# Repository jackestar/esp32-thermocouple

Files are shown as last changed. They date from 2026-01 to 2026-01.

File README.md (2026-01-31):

<h3 align="center">ESP32-S2 Based Thermocouple Dirver</h3>

<div align="center">
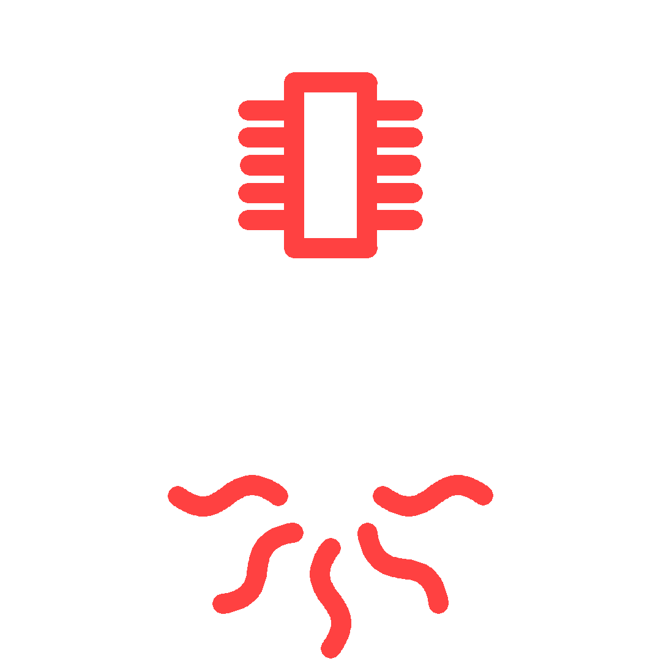
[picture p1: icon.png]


</div>

### Materials

* ESP32-S2
* LM356
* AD620AN
* ~~LM35~~
* [TC33X-2-103E](https://componentsearchengine.com/part-view/TC33X-2-103E/Bourns) (or equivalent footprint)

### Proyect Structure

**IDF code**
FLAGS: 
 * TEST (breadboard/PCB)
 * DEBUG (SERIAL OUTPUT)

**Kicad**

> The last version is made for a 1-wire temperature module, the PCB can include LM35/LM335 like the example in [Commit 6ab5541](https://github.com/jackestar/esp32-thermocouple/commit/6ab55410f83fd76fe158129e17a911ef169d20fd)

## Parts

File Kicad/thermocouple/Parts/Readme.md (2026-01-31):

[TC33X-2-103E](https://componentsearchengine.com/part-view/TC33X-2-103E/Bourns) (or equivalent footprint)

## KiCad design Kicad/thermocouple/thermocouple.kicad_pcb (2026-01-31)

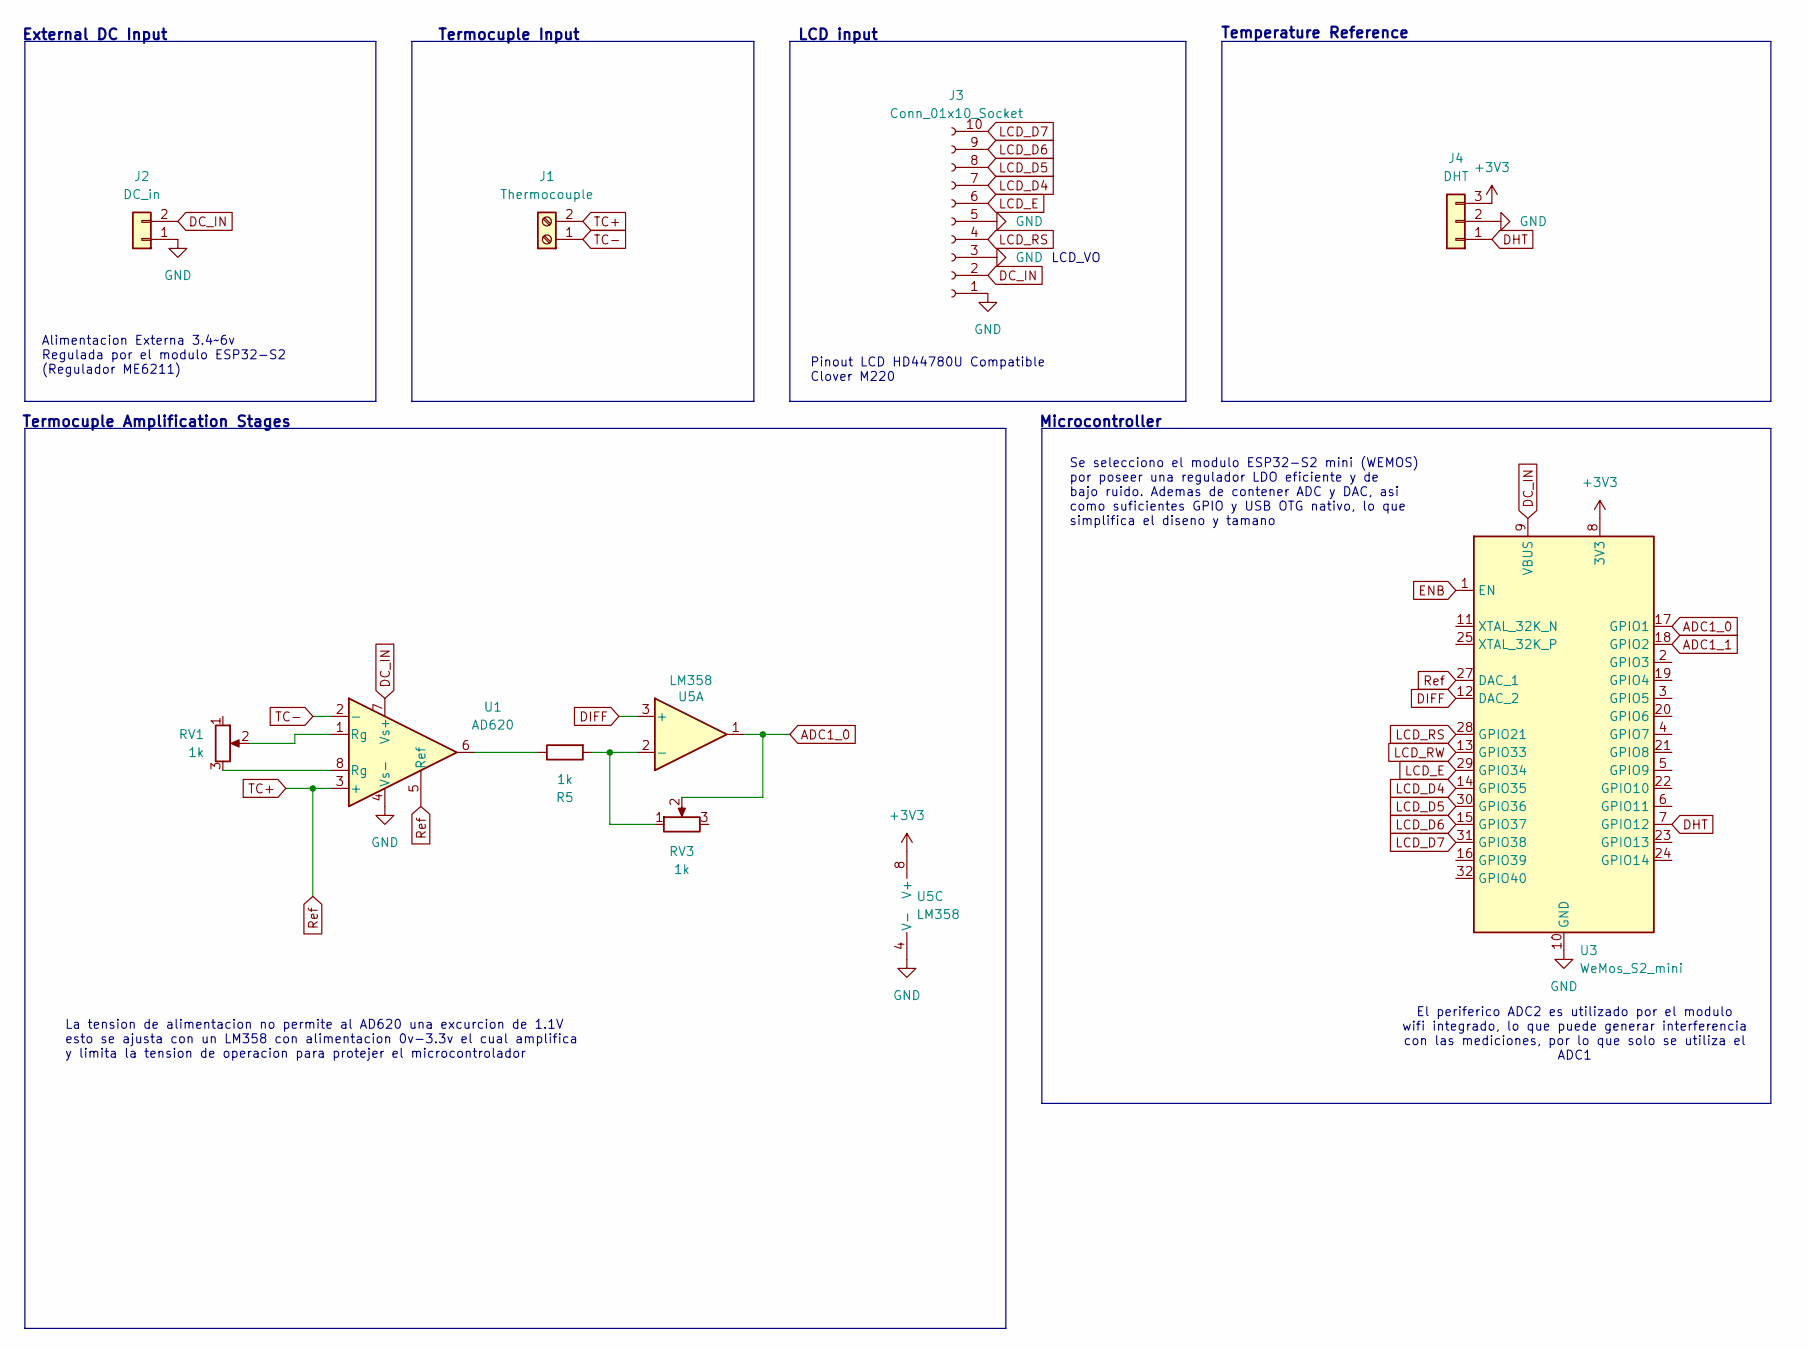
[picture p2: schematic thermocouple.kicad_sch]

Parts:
J1: Thermocouple; TerminalBlock_MaiXu_MX126-5.0-02P_1x02_P5.00mm
J2: DC_in; PinHeader_1x02_P2.54mm_Vertical
J3: Conn_01x10_Socket; PinSocket_1x10_P2.54mm_Vertical
J4: DHT; PinHeader_1x03_P2.54mm_Vertical
R5: 1k; R_1206_3216Metric_Pad1.30x1.75mm_HandSolder
RV1, RV3: 1k; Potentiometer_Bourns_TC33X_Vertical
U1: AD620; DIP-8_W7.62mm_Socket_LongPads
U3: WeMos_S2_mini; WEMOS_S2_mini
U5: LM358; SOIC-8_3.9x4.9mm_P1.27mm

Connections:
+3V3: J4.3, U3.8 (3V3), U5.8 (V+)
ADC1_0: RV3.2, U3.17 (GPIO1), U5.1
ADC1_1: U3.18 (GPIO2)
DC_IN: J2.2, J3.2, U1.7 (Vs+), U3.9 (VBUS)
DHT: J4.1, U3.7 (GPIO12)
DIFF: U3.12 (DAC_2), U5.3 (+)
ENB: U3.1 (EN)
GND: J2.1, J3.1, J3.3, J3.5, J4.2, U1.4 (Vs-), U3.10 (GND), U3.26 (GND), U5.4 (V-)
LCD_D4: J3.7, U3.14 (GPIO35)
LCD_D5: J3.8, U3.30 (GPIO36)
LCD_D6: J3.9, U3.15 (GPIO37)
LCD_D7: J3.10, U3.31 (GPIO38)
LCD_E: J3.6, U3.29 (GPIO34)
LCD_RS: J3.4, U3.28 (GPIO21)
LCD_RW: U3.13 (GPIO33)
unnamed: R5.1, U1.6
unnamed: RV1.2, U1.1 (Rg)
unnamed: RV1.3, U1.8 (Rg)
unnamed: R5.2, RV3.1, U5.2 (-)
Ref: J1.2, U1.3 (+), U1.5 (Ref), U3.27 (DAC_1)
TC-: J1.1, U1.2 (-)

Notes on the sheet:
Termocuple Input
LCD input
La tension de alimentacion no permite al AD620 una excurcion de 1.1V esto se ajusta con un LM358 con alimentacion 0v-3.3v el cual amplifica y limita la tension de operacion para protejer el microcontrolador
Se selecciono el modulo ESP32-S2 mini (WEMOS) por poseer una regulador LDO eficiente y de bajo ruido. Ademas de contener ADC y DAC, asi como suficientes GPIO y USB OTG nativo, lo que simplifica el diseno y tamano
External DC Input
Microcontroller
Alimentacion Externa 3.4~6v Regulada por el modulo ESP32-S2 (Regulador ME6211)
LCD_VO
Termocuple Amplification Stages
Temperature Reference
Pinout LCD HD44780U Compatible Clover M220
El periferico ADC2 es utilizado por el modulo wifi integrado, lo que puede generar interferencia con las mediciones, por lo que solo se utiliza el ADC1

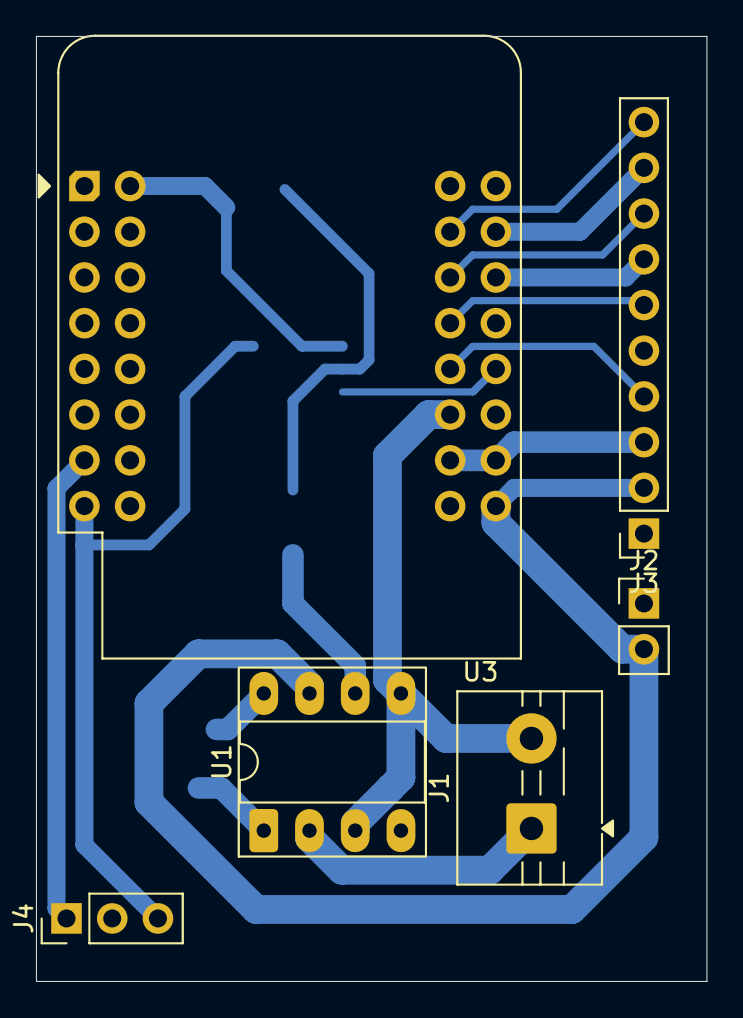
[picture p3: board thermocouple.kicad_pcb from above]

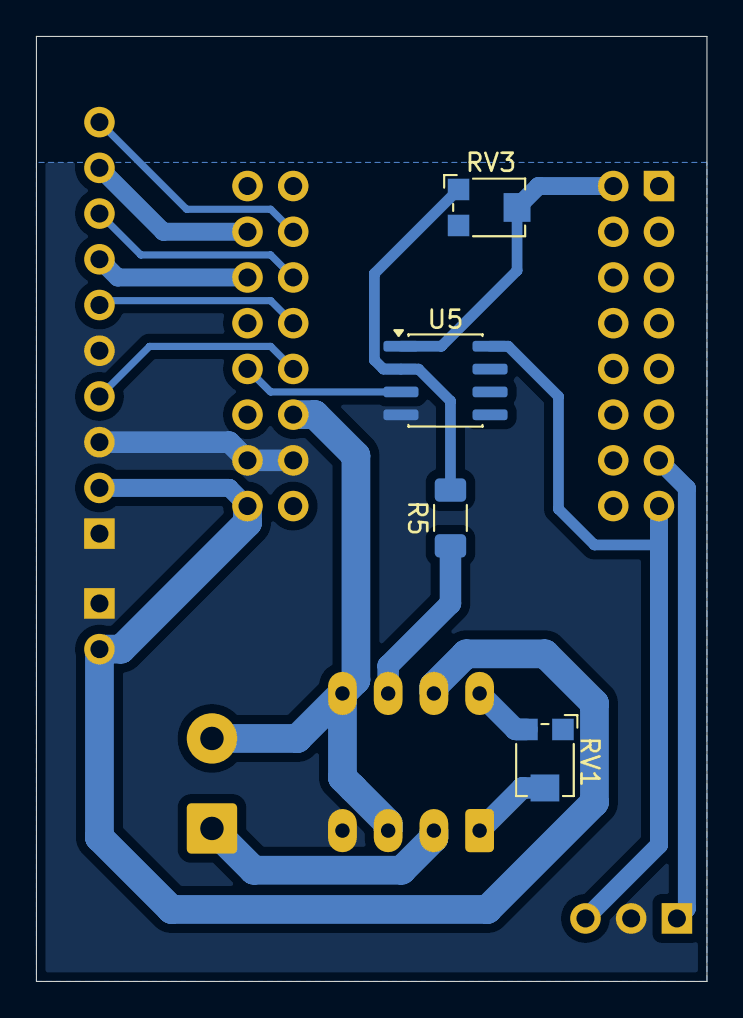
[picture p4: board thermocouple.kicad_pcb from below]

Board: 2 copper layers, 37.2 x 52.5 mm, 10 parts (4 on the bottom side), 18 nets.

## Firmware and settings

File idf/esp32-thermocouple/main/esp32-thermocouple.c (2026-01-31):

#include <stdio.h>
#include <inttypes.h>
#include <stdlib.h>

#include <hd44780.h>
#include <esp_idf_lib_helpers.h>

#include <freertos/FreeRTOS.h>
#include <freertos/task.h>
#include <freertos/semphr.h>

#include "esp_adc/adc_oneshot.h"
#include "esp_check.h"
#include "esp_log.h"

#include "dht.h"

#include "driver/dac_oneshot.h"
#include "nvs_flash.h"
#include "esp_netif.h"
#include "esp_event.h"
#include "esp_wifi.h"
#include "esp_http_server.h"
#include "esp_err.h"
#include <string.h>

uint8_t DAC_DIFF = 115; //180
uint8_t DAC_VGND = 215;

float TER_BIAS = 408.4583; // 0-max_raw
int TER_PROP = -568.8889;

// Breadboard test have another easier pin out
#define TEST

#ifdef TEST

#define TER_ADC 8
#define AMB_DHT 5

hd44780_t lcd = {
    .write_cb = NULL,
    .font = HD44780_FONT_5X8,
    .lines = 2,
    .pins = {
        .rs = GPIO_NUM_7,
        .e = GPIO_NUM_3,
        .d4 = GPIO_NUM_8,
        .d5 = GPIO_NUM_6,
        .d6 = GPIO_NUM_4,
        .d7 = GPIO_NUM_2,
        .bl = HD44780_NOT_USED}};

#else

#define TER_ADC 2
#define AMB_DHT 4

hd44780_t lcd = {
    .write_cb = NULL,
    .font = HD44780_FONT_5X8,
    .lines = 2,
    .pins = {
        .rs = GPIO_NUM_21,
        .e = GPIO_NUM_34,
        .d4 = GPIO_NUM_35,
        .d5 = GPIO_NUM_36,
        .d6 = GPIO_NUM_37,
        .d7 = GPIO_NUM_38,
        .bl = HD44780_NOT_USED}};

#define TER_ADC 2
#define AMB_DHT 4

#define LCD_RW 33
#define LCD_VO 16

#endif

#define EXAMPLE_DAC_CHAN0_ADC_CHAN ADC_CHANNEL_6 // GPIO17, same as DAC channel 0
#define EXAMPLE_DAC_CHAN1_ADC_CHAN ADC_CHANNEL_7 // GPIO18, same as DAC channel 1

#define debug 1

static const uint8_t amb_sym[8] = {0b00000100,
                                   0b00000100,
                                   0b00011111,
                                   0b00001110,
                                   0b00000100,
                                   0b00011111,
                                   0b00000100,
                                   0b00000100};
static const uint8_t ter_sym[8] = {0b00011000,
                                   0b00000100,
                                   0b00000010,
                                   0b00000001,
                                   0b00000010,
                                   0b00000100,
                                   0b00011000,
                                   0b00000000};
static const uint8_t cen_sym[8] = {0b00011000,
                                   0b00011000,
                                   0b00000011,
                                   0b00000100,
                                   0b00000100,
                                   0b00000100,
                                   0b00000011,
                                   0b00000000};

float amb_tem = 27.00;
float ter_tem = 27.00;
float ADC_ACUM = 0;
static adc_oneshot_unit_handle_t adc_handle = NULL;
static dac_oneshot_handle_t dac_chan0_handle = NULL;
static dac_oneshot_handle_t dac_chan1_handle = NULL;

/* Webserver / Wi-Fi globals */
static httpd_handle_t server = NULL;
static SemaphoreHandle_t config_mutex = NULL;

/* Simple root page (no styling) */
static const char *index_html =
    "<!doctype html>"
    "<html><head><meta charset=\"utf-8\"></head><body>"
    "<h3>ESP32 Thermocouple</h3>"
    "<div>Ambient: <span id=\"amb\">--</span> &deg;C</div>"
    "<div>Thermocouple: <span id=\"ter\">--</span> &deg;C</div>"
    "<hr>"
    "<div>DAC_DIFF: <input id=\"DAC_DIFF_in\" size=6> <p id=\"DAC_DIFF_val\">--</p></div>"
    "<div>DAC_VGND: <input id=\"DAC_VGND_in\" size=6> <p id=\"DAC_VGND_val\">--</p></div>"
    "<div>TER_BIAS: <input id=\"TER_BIAS_in\" size=6> <p id=\"TER_BIAS_val\">--</p></div>"
    "<div>TER_PROP: <input id=\"TER_PROP_in\" size=6> <p id=\"TER_PROP_val\">--</p></div>"
    "<div>ADC_ACUM: <input id=\"ADC_ACUM_in\" size=8> <p id=\"ADC_ACUM_val\">--</p></div>"
    "<div><button onclick=\"apply()\">Apply</button></div>"
    "<script>"
    "async function fetchState(){"
    " const r=await fetch('/api/state');"
    " const j=await r.json();"
    " document.getElementById('amb').textContent=j.amb_tem.toFixed(2);"
    " document.getElementById('ter').textContent=j.ter_tem.toFixed(2);"
    " document.getElementById('DAC_DIFF_val').textContent = j.DAC_DIFF;"
    " document.getElementById('DAC_VGND_val').textContent = j.DAC_VGND;"
    " document.getElementById('TER_BIAS_val').textContent = j.TER_BIAS.toFixed(2);"
    " document.getElementById('TER_PROP_val').textContent = j.TER_PROP.toFixed(2);"
    " document.getElementById('ADC_ACUM_val').textContent = j.ADC_ACUM.toFixed(3);"
    "}"
    "async function apply(){"
    " const params=[];"
    " const mappings=[['DAC_DIFF_in','DAC_DIFF'],['DAC_VGND_in','DAC_VGND'],['TER_BIAS_in','TER_BIAS'],['TER_PROP_in','TER_PROP'],['ADC_ACUM_in','ADC_ACUM']];"
    " mappings.forEach(pair=>{ const v=document.getElementById(pair[0]).value; if(v!=='') params.push(encodeURIComponent(pair[1])+'='+encodeURIComponent(v)); });"
    " await fetch('/api/set?'+params.join('&'));"
    " setTimeout(fetchState,200);"
    "}"
    "setInterval(fetchState,1000); fetchState();"
    "</script>"
    "</body></html>";

/* Handler: root page */
static esp_err_t root_get_handler(httpd_req_t *req)
{
    httpd_resp_set_type(req, "text/html");
    httpd_resp_send(req, index_html, HTTPD_RESP_USE_STRLEN);
    return ESP_OK;
}

/* Handler: /api/state -> JSON with current values */
static esp_err_t api_state_get_handler(httpd_req_t *req)
{
    char buf[256];
    float dac_diff, dac_vgnd, ter_bias, ter_prop, adc_acum, amb, ter;

    if (config_mutex) xSemaphoreTake(config_mutex, portMAX_DELAY);
    dac_diff = DAC_DIFF;
    dac_vgnd = DAC_VGND;
    ter_bias = TER_BIAS;
    ter_prop = TER_PROP;
    adc_acum = ADC_ACUM;
    amb = amb_tem;
    ter = ter_tem;
    if (config_mutex) xSemaphoreGive(config_mutex);

    int len = snprintf(buf, sizeof(buf), "{\"DAC_DIFF\":%.0f,\"DAC_VGND\":%.0f,\"TER_BIAS\":%.2f,\"TER_PROP\":%.2f,\"ADC_ACUM\":%.3f,\"amb_tem\":%.2f,\"ter_tem\":%.2f}", dac_diff, dac_vgnd, ter_bias, ter_prop, adc_acum, amb, ter);
    httpd_resp_set_type(req, "application/json");
    httpd_resp_send(req, buf, len);
    return ESP_OK;
}

/* Handler: /api/set?KEY=VALUE&... -> update variables */
static esp_err_t api_set_get_handler(httpd_req_t *req)
{
    char buf[256];
    if (httpd_req_get_url_query_str(req, buf, sizeof(buf)) == ESP_OK)
    {
        char val[64];
        if (config_mutex) xSemaphoreTake(config_mutex, portMAX_DELAY);

        if (httpd_query_key_value(buf, "DAC_DIFF", val, sizeof(val)) == ESP_OK)
            DAC_DIFF = (uint8_t)atoi(val);
        if (httpd_query_key_value(buf, "DAC_VGND", val, sizeof(val)) == ESP_OK)
            DAC_VGND = (uint8_t)atoi(val);
        if (httpd_query_key_value(buf, "TER_BIAS", val, sizeof(val)) == ESP_OK)
            TER_BIAS = atof(val);
        if (httpd_query_key_value(buf, "TER_PROP", val, sizeof(val)) == ESP_OK)
            TER_PROP = atoi(val);
        if (httpd_query_key_value(buf, "ADC_ACUM", val, sizeof(val)) == ESP_OK)
            ADC_ACUM = atof(val);

        if (config_mutex) xSemaphoreGive(config_mutex);
    }

    httpd_resp_sendstr(req, "OK");
    return ESP_OK;
}

/* Start the webserver and register URIs */
static httpd_handle_t start_webserver(void)
{
    httpd_config_t config = HTTPD_DEFAULT_CONFIG();
    httpd_handle_t server = NULL;
    if (httpd_start(&server, &config) == ESP_OK)
    {
        httpd_uri_t uri_root = {
            .uri = "/",
            .method = HTTP_GET,
            .handler = root_get_handler,
            .user_ctx = NULL};
        httpd_register_uri_handler(server, &uri_root);

        httpd_uri_t uri_state = {
            .uri = "/api/state",
            .method = HTTP_GET,
            .handler = api_state_get_handler,
            .user_ctx = NULL};
        httpd_register_uri_handler(server, &uri_state);

        httpd_uri_t uri_set = {
            .uri = "/api/set",
            .method = HTTP_GET,
            .handler = api_set_get_handler,
            .user_ctx = NULL};
        httpd_register_uri_handler(server, &uri_set);
    }
    return server;
}

/* Wi-Fi soft AP initializer (open AP) */
static void wifi_init_softap(void)
{
    esp_err_t ret = nvs_flash_init();
    if (ret == ESP_ERR_NVS_NO_FREE_PAGES || ret == ESP_ERR_NVS_NEW_VERSION_FOUND) {
        nvs_flash_erase();
        nvs_flash_init();
    }

    esp_netif_init();
    esp_event_loop_create_default();
    esp_netif_create_default_wifi_ap();

    wifi_init_config_t cfg = WIFI_INIT_CONFIG_DEFAULT();
    esp_wifi_init(&cfg);

    wifi_config_t wifi_config = {0};
    snprintf((char *)wifi_config.ap.ssid, sizeof(wifi_config.ap.ssid), "%s", "ESP32_THERMO");
    wifi_config.ap.ssid_len = strlen("ESP32_THERMO");
    wifi_config.ap.channel = 1;
    wifi_config.ap.max_connection = 4;
    wifi_config.ap.authmode = WIFI_AUTH_OPEN;

    esp_wifi_set_mode(WIFI_MODE_AP);
    esp_wifi_set_config(WIFI_IF_AP, &wifi_config);
    esp_wifi_start();
}

void lcd_config()
{
    ESP_ERROR_CHECK(hd44780_init(&lcd));
}

void dht_task(void *pvParameters)
{
    gpio_set_pull_mode(AMB_DHT, GPIO_PULLUP_ONLY);
    while (1)
    {
        ESP_ERROR_CHECK(dht_read_float_data(DHT_TYPE_AM2301, AMB_DHT, NULL, &amb_tem));
        vTaskDelay(pdMS_TO_TICKS(2000));
    }
}

void lcd_task(void *pvParameters)
{
    hd44780_upload_character(&lcd, 0, amb_sym);
    hd44780_upload_character(&lcd, 1, ter_sym);
    hd44780_upload_character(&lcd, 2, cen_sym);

    hd44780_gotoxy(&lcd, 0, 0);
    hd44780_puts(&lcd, "\x08      \x0A");
    hd44780_gotoxy(&lcd, 0, 1);
    hd44780_puts(&lcd, "\x09      \x0A");

    while (1)
    {
        char buf[16];

        hd44780_gotoxy(&lcd, 2, 1);
        snprintf(buf, sizeof(buf), "%.2f", ter_tem);
        buf[sizeof(buf) - 1] = 0;
        hd44780_puts(&lcd, buf);

        hd44780_gotoxy(&lcd, 2, 0);
        snprintf(buf, sizeof(buf), "%.2f", amb_tem);
        buf[sizeof(buf) - 1] = 0;
        hd44780_puts(&lcd, buf);

        vTaskDelay(pdMS_TO_TICKS(250));
    }
}

#define BLINK_GPIO 15

void led_blink(void *pvParameters)
{
    gpio_reset_pin(BLINK_GPIO);
    gpio_set_direction(BLINK_GPIO, GPIO_MODE_OUTPUT);

    while (1)
    {
        // Turn LED ON
        gpio_set_level(BLINK_GPIO, 1);
        vTaskDelay(1000 / portTICK_PERIOD_MS); // Delay 1 second

        // Turn LED OFF
        gpio_set_level(BLINK_GPIO, 0);
        vTaskDelay(1000 / portTICK_PERIOD_MS); // Delay 1 second
    }
}

#define SPS 100

void adc_task(void *pvParameters)
{
    printf("ADC task\n");
    adc_oneshot_chan_cfg_t chan_cfg = {
        .bitwidth = ADC_BITWIDTH_DEFAULT,
        .atten = ADC_ATTEN_DB_12,
    };

    ESP_ERROR_CHECK(adc_oneshot_config_channel(adc_handle, TER_ADC, &chan_cfg));
    printf("ADC task: LOOP\n");
    int acumulator[SPS] = {0};
    uint8_t counter = 0;
    while (1)
    {
        int raw = 0;
        esp_err_t ret = adc_oneshot_read(adc_handle, TER_ADC, &raw);
        if (ret == ESP_OK)
        {
            const int max_raw = 8192; /* 13-bit resolution */

            counter++;
            if (counter == SPS)
                counter = 0;

            acumulator[counter] = raw;
            if (counter == SPS - 1)
            {
                ADC_ACUM = 0;
                for (uint8_t i = 0; i < SPS; i++)
                    ADC_ACUM += acumulator[i];
                ADC_ACUM /= SPS;

                const float cast = (max_raw - ADC_ACUM) * TER_PROP;
                ter_tem = amb_tem + TER_BIAS + cast / max_raw;

                if (debug)
                {
                    printf("ADC %f\n", ADC_ACUM);
                    printf("AMB %f\n", amb_tem);
                }
            }
        }
        else
        {
            printf("ADC task fail!!!\n");
            ESP_LOGW("adc_task", "adc read failed: %d", ret);
        }

        vTaskDelay(pdMS_TO_TICKS(1000 / SPS));
    }
}

void dac_update_task(void *pvParameters)
{
    while (1)
    {
        uint8_t diff = 0, vgnd = 0;
        if (config_mutex) xSemaphoreTake(config_mutex, portMAX_DELAY);
        diff = DAC_DIFF;
        vgnd = DAC_VGND;
        if (config_mutex) xSemaphoreGive(config_mutex);

        if (dac_chan0_handle)
            ESP_ERROR_CHECK(dac_oneshot_output_voltage(dac_chan0_handle, diff));
        if (dac_chan1_handle)
            ESP_ERROR_CHECK(dac_oneshot_output_voltage(dac_chan1_handle, vgnd));

        vTaskDelay(pdMS_TO_TICKS(200));
    }
}

void app_main(void)
{
    /* DAC oneshot init */
    dac_oneshot_config_t chan0_cfg = {
        .chan_id = DAC_CHAN_0,
    };
    ESP_ERROR_CHECK(dac_oneshot_new_channel(&chan0_cfg, &dac_chan0_handle));

    dac_oneshot_config_t chan1_cfg = {
        .chan_id = DAC_CHAN_1,
    };
    ESP_ERROR_CHECK(dac_oneshot_new_channel(&chan1_cfg, &dac_chan1_handle));

    lcd_config();
    xTaskCreate(lcd_task, "lcd_task", configMINIMAL_STACK_SIZE * 3, NULL, 5, NULL);
    xTaskCreate(led_blink, "led_blink", configMINIMAL_STACK_SIZE * 3, NULL, 5, NULL);

    adc_oneshot_unit_init_cfg_t init_cfg = {
        .unit_id = ADC_UNIT_1,
        .ulp_mode = ADC_ULP_MODE_DISABLE,
    };
    ESP_ERROR_CHECK(adc_oneshot_new_unit(&init_cfg, &adc_handle));

    xTaskCreate(adc_task, "adc_task", configMINIMAL_STACK_SIZE * 3, NULL, 5, NULL);
    xTaskCreate(dht_task, "dht_task", configMINIMAL_STACK_SIZE * 3, NULL, 5, NULL);

    /* Create mutex for protecting config/state shared with web handlers */
    config_mutex = xSemaphoreCreateMutex();

    /* Start Wi-Fi soft AP and webserver */
    wifi_init_softap();
    server = start_webserver();

    /* Start DAC updater task */
    xTaskCreate(dac_update_task, "dac_update", configMINIMAL_STACK_SIZE * 2, NULL, 5, NULL);
}

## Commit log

2026-01-22 Added Kicad, fix some idf issues
    [thermocouple.kicad_pcb, thermocouple.kicad_sch]
2026-01-25 TestCircuit DAC configured
    [thermocouple.kicad_sch]
2026-01-31 Release Update readme Added wifi interface Add wifi UI Calibration Add DAC
    [thermocouple.kicad_pcb, thermocouple.kicad_sch]
